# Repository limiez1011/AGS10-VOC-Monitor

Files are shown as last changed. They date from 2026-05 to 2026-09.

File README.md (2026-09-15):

[air quality monitor-bom.csv](https://github.com/user-attachments/files/27851702/air.quality.monitor-bom.csv)
# AGS10-VOC-Monitor
Battery-powered indoor air quality monitor that reads VOC every 60 seconds and displays it on an e-ink screen.

## Functionality
It uses an AGS10 TVOC sensor which samples the air every 60 seconds, when it's not sampling it goes into a sleep mode where the resistive heater turns off, the PCB includes an MCP73831 which charges LiPo batteries at 0.5A which is perfect for a 500mAh or 800mAh LiPo (1C/0.625C charge rate) The MCU is the seeed studios RP2040 which has a trace going from BATT+ to an ADC pin with a voltage divider so that we can know when to charge the batteries. The sample is then displayed on a 2.66in E-ink which is also updated every 60 seconds, It displays voltage and ppb.

## Bill of Materials
### (2 PCBS)
|Name |Purpose |Quantity|Total Cost (USD)|Link |Distributor|
|---|---|---|---|---|---|
|Passives |Caps,Resistors,Diodes|22 |1.00 | [link](https://jlcpcb.com/parts) |JLCPCB |
|MICROCHIP MCP73831T-2ATI/OT|lipo charger |2 |2.40 | [link](https://jlcpcb.com/partdetail/MicrochipTech-MCP73831T_2ATIOT/C14879) |JLCPCB |
|AGS10 |VOC sensor |2 |3.20 | [link](https://jlcpcb.com/partdetail/AGS10/C3012632) |JLCPCB |
|SEEED rp2040 |MCU |2 |11.30 | [link](https://www.tme.eu/ro/details/seeed-102010428/kituri-de-dezvoltare-altele/seeed-studio/xiao-rp2040/) |TME EU |
|PCB |PCBA |5 |17.00 | [link](https://jlcpcb.com/pcb-assembly) |JLCPCB |
|Waveshare 18321 |eink display |1 |14.28 | [link](https://www.tme.eu/ro/details/wsh-18321/hartie-electronica/waveshare/18321)|TME EU |

## Photos






## Build photos






## Build Instructions

- Create PCB jig
- Apply solder paste using stencil
- place components
- add to hotplate to melt solder
- solder mcu + eink
- flash firmware by pressing boot and adding the firmware file to the root directory
  and thats all.

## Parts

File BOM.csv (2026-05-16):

Name | Purpose | Quantity | Total Cost (USD) | Link | Distributor
Passives | Caps,Resistors,Diodes | 22 | 1.00 | https://jlcpcb.com/parts | JLCPCB
MICROCHIP MCP73831T-2ATI/OT | lipo charger | 2 | 2.40 | https://jlcpcb.com/partdetail/MicrochipTech-MCP73831T_2ATIOT/C14879 | JLCPCB
AGS10 | VOC sensor | 2 | 3.20 | https://jlcpcb.com/partdetail/AGS10/C3012632 | JLCPCB
SEEED rp2040 | MCU | 2 | 11.30 | https://www.tme.eu/ro/details/seeed-102010428/kituri-de-dezvoltare-altele/seeed-studio/xiao-rp2040/ | TME EU
PCB | PCBA | 5 | 17.00 | https://jlcpcb.com/pcb-assembly | JLCPCB
Waveshare 18321 | eink display | 1 | 14.28 | https://www.tme.eu/ro/details/wsh-18321/hartie-electronica/waveshare/18321/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 | TME EU

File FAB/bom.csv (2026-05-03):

Designator | Footprint | Quantity | Value | LCSC Part #
C1 | 402 | 1 | 100nF | C1525
C3, C4 | 603 | 2 | 4.7uF | C19666
D1 | 603 | 1 | LED_Small | C2286
D2 | SOD-123 | 1 | D_Schottky_Small | C8598
R1, R2 | 402 | 2 | 4.7K | C25900
R3 | 402 | 1 | 2K | C4109
R4 | 402 | 1 | 470 | C25117
R5, R6 | 402 | 2 | 100K | C25741
U1 | AGS10 | 1 | ~ | C3012632
U3 | SOT95P280X145-5N | 1 | MCP73831T-2ACI_OT | C14879

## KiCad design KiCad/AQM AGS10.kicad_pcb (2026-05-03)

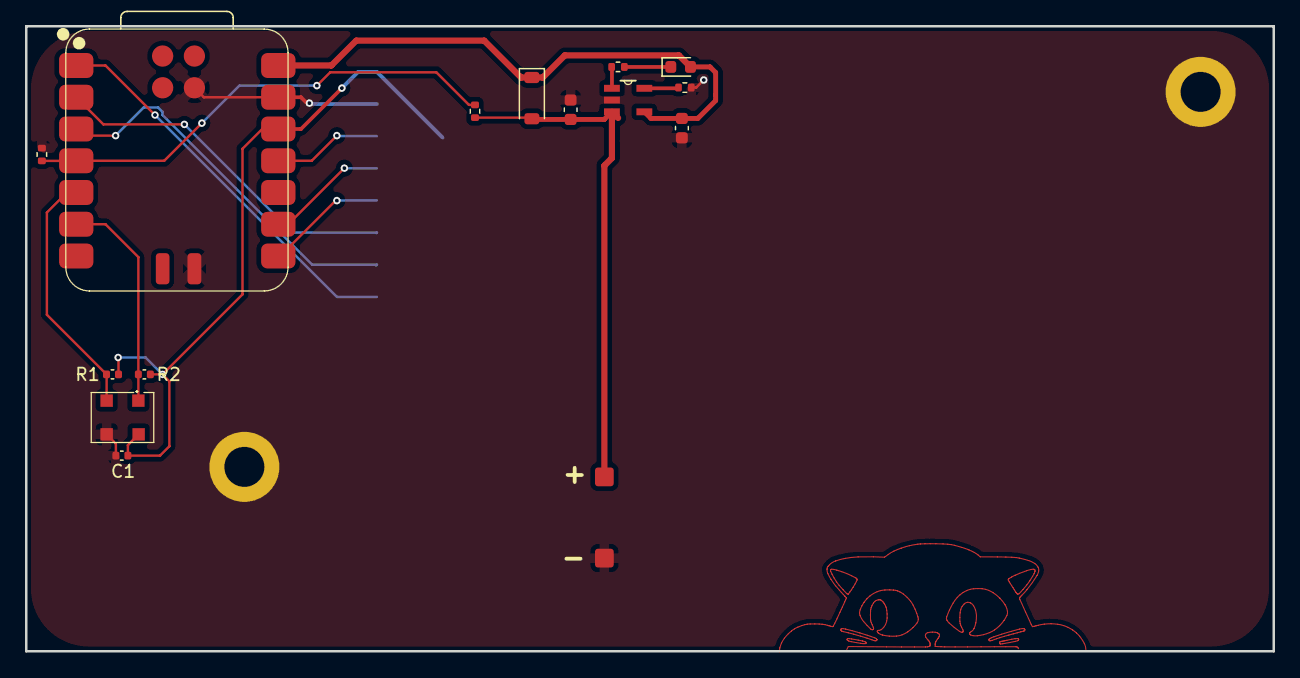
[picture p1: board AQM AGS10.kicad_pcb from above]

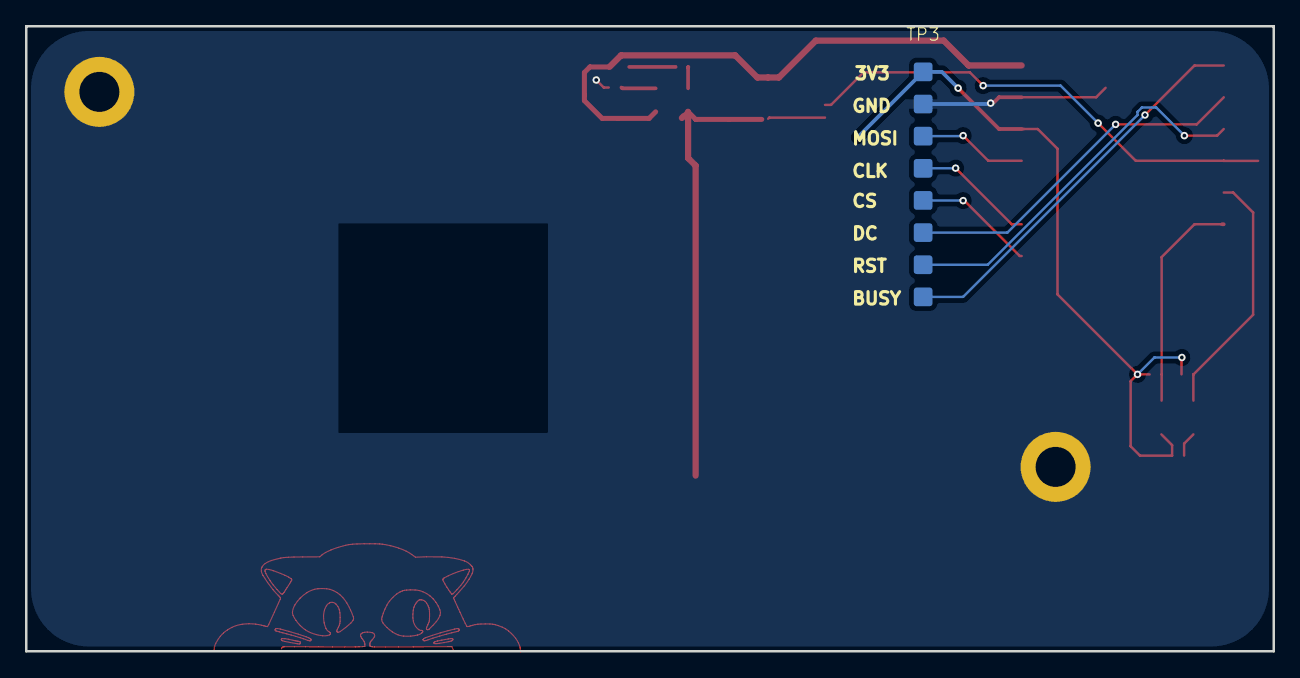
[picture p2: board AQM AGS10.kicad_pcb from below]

Board: 2 copper layers, 99.8 x 50.0 mm, 26 parts (8 on the bottom side), 16 nets.

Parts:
C1: 100nF; C_0402_1005Metric
C3, C4: 4.7uF; C_0603_1608Metric
D1: LED_Small; LED_0603_1608Metric
D2: D_Schottky_Small; D_SOD-123
H3, H4: MountingHole_Pad; MountingHole_3.2mm_M3_DIN965_Pad
R1, R2: 4.7K; C_0402_1005Metric
R3: 2K; R_0402_1005Metric
R4: 470; R_0402_1005Metric
R5, R6: 100K; R_0402_1005Metric
TP1: BATT-; padround
TP2, TP3, TP4, TP5, TP6, TP7, TP8, TP9, TP10: BATT+; padround
U1: AGS10
U2: XIAO-RP2040-SMD
U3: MCP73831T-2ACI_OT; SOT95P280X145-5N

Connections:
+3V3: C1.2, R1.1, R2.1, TP3.1 (1_1), U1.4, U2.12 (3V3)
+5V: C3.1, D1.2 (A), D2.1 (K), U2.14 (5V), U3.4 (VDD)
/BAT: C4.1, D2.2 (A), R5.1, TP2.1 (1_1), U3.3 (VBAT)
/BUSY: TP10.1 (1_1), U2.1 (GPIO26_A0_D0)
/CS: TP7.1 (1_1), U2.8 (GPIO1_D7_CSn_RX)
/DC: TP8.1 (1_1), U2.2 (GPIO27_A1_D1)
/MOSI: TP5.1 (1_1), U2.11 (GPIO3_D10_MOSI)
/RST: TP9.1 (1_1), U2.3 (GPIO28_A2_D2)
/SCL: R2.2, U1.1, U2.6 (GPIO7_D5_SCL)
/SCLK: TP6.1 (1_1), U2.9 (GPIO2_D8_SCK)
/SDA: R1.2, U1.2, U2.5 (GPIO6_D4_SDA)
/STAT: R4.2, U3.1 (STAT)
GND: C1.1, C3.2, C4.2, H3.1 (1_1), H4.1 (1_1), R3.2, R6.2, TP1.1 (1_1), TP4.1 (1_1), U1.3, U2.13 (GND), U2.16 (GND), U2.20 (GND), U3.2 (VSS)
unnamed: D1.1 (K), R4.1
unnamed: R5.2, R6.1, U2.4 (GPIO29_A3_D3)
unnamed: R3.1, U3.5 (PROG)

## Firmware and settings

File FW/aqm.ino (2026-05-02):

#include <Arduino.h>
#include <Wire.h>
#include <SPI.h>
#include <GxEPD2_BW.h>
#include <Fonts/FreeSans9pt7b.h>
#include <Fonts/FreeSansBold18pt7b.h>

#define EPD_CS    1
#define EPD_DC    27
#define EPD_RST   28
#define EPD_BUSY  26
#define AGS_SDA   6
#define AGS_SCL   7
#define BAT_PIN   29
#define LED_R     17
#define LED_G     16
#define LED_B     25

#define DISPLAY_INTERVAL_MS  60000UL
#define LOW_BAT_V            3.5f
#define LOW_BAT_FLASH_MS     100U
#define ADC_REF_V            3.3f
#define ADC_RES              4095.0f
#define BAT_DIVIDER          2.0f

#define AGS10_ADDR      0x1A
#define AGS10_REG_TVOC  0x00
#define AGS10_STATUS_OK 0x00
#define AGS10_WARMING   0x01

GxEPD2_BW<GxEPD2_266_GDEY0266T90, GxEPD2_266_GDEY0266T90::HEIGHT> display(
  GxEPD2_266_GDEY0266T90(EPD_CS, EPD_DC, EPD_RST, EPD_BUSY)
);

float         batV          = 0;
bool          lowBat        = false;
uint32_t      tvocPpb       = 0;
bool          warming        = true;
unsigned long lastDisplayMs = 0;

void ledOff() {
  digitalWrite(LED_R, HIGH);
  digitalWrite(LED_G, HIGH);
  digitalWrite(LED_B, HIGH);
}

void flashLed(bool r, bool g, bool b, uint16_t ms) {
  digitalWrite(LED_R, r ? LOW : HIGH);
  digitalWrite(LED_G, g ? LOW : HIGH);
  digitalWrite(LED_B, b ? LOW : HIGH);
  delay(ms);
  ledOff();
}

float readBatV() {
  uint32_t sum = 0;
  for (int i = 0; i < 8; i++) {
    sum += analogRead(BAT_PIN);
    delay(2);
  }
  return (sum / 8.0f / ADC_RES) * ADC_REF_V * BAT_DIVIDER;
}


uint8_t crc8(const uint8_t* data, uint8_t len) {
  uint8_t crc = 0xFF;
  for (uint8_t i = 0; i < len; i++) {
    crc ^= data[i];
    for (uint8_t b = 0; b < 8; b++) {
      crc = (crc & 0x80) ? (crc << 1) ^ 0x31 : (crc << 1);
    }
  }
  return crc;
}


bool readAgs10() {
  Wire.beginTransmission(AGS10_ADDR);
  Wire.write(AGS10_REG_TVOC);
  if (Wire.endTransmission(false) != 0) return false;

  if (Wire.requestFrom(AGS10_ADDR, (uint8_t)5) != 5) return false;

  uint8_t buf[5];
  for (int i = 0; i < 5; i++) buf[i] = Wire.read();

  if (crc8(buf, 4) != buf[4]) return false;

  warming  = (buf[0] == AGS10_WARMING);
  tvocPpb  = ((uint32_t)buf[1] << 16) | ((uint32_t)buf[2] << 8) | buf[3];

  return true;
}

const char* tvocLabel(uint32_t ppb) {
  if (ppb <= 220)  return "Excellent";
  if (ppb <= 660)  return "Good";
  if (ppb <= 1430) return "Moderate";
  if (ppb <= 2200) return "Poor";
  return "Very poor";
}

void updateDisplay() {
  display.setFullWindow();
  display.firstPage();
  do {
    display.fillScreen(GxEPD_WHITE);
    display.setTextColor(GxEPD_BLACK);
    display.setTextWrap(false);

    display.setFont(&FreeSans9pt7b);

  
    display.setCursor(4, 14);
    display.print(batV, 2);
    display.print("V");
    if (lowBat) {
      display.setCursor(50, 14);
      display.print(" LOW");
    }

 
    if (warming) {
      display.setCursor(display.width() - 76, 14);
      display.print("Warming up");
    }

    display.drawLine(0, 20, display.width(), 20, GxEPD_BLACK);

 
    display.setFont(&FreeSansBold18pt7b);
    char tvocStr[12];
    if (warming) {
      snprintf(tvocStr, sizeof(tvocStr), "---");
    } else {
      snprintf(tvocStr, sizeof(tvocStr), "%lu", tvocPpb);
    }
    int16_t x1, y1;
    uint16_t w, h;
    display.getTextBounds(tvocStr, 0, 0, &x1, &y1, &w, &h);
    display.setCursor((display.width() - w) / 2, 72);
    display.print(tvocStr);


    display.setFont(&FreeSans9pt7b);
    display.getTextBounds("ppb", 0, 0, &x1, &y1, &w, &h);
    display.setCursor((display.width() - w) / 2, 92);
    display.print("ppb");

    display.drawLine(0, 100, display.width(), 100, GxEPD_BLACK);


    const char* label = warming ? "Warming up..." : tvocLabel(tvocPpb);
    display.getTextBounds(label, 0, 0, &x1, &y1, &w, &h);
    display.setCursor((display.width() - w) / 2, 130);
    display.print(label);

  } while (display.nextPage());

  display.powerOff();
}

void setup() {
  pinMode(LED_R, OUTPUT);
  pinMode(LED_G, OUTPUT);
  pinMode(LED_B, OUTPUT);
  ledOff();
  analogReadResolution(12);

  Wire.setSDA(AGS_SDA);
  Wire.setSCL(AGS_SCL);
  Wire.begin();

  display.init(0);
  display.setRotation(1);


  Wire.beginTransmission(AGS10_ADDR);
  if (Wire.endTransmission() != 0) {
    while (true) { flashLed(true, false, false, 300); delay(300); }
  }

  flashLed(false, true, false, 200);
}

void loop() {
  unsigned long now = millis();

  if (now - lastDisplayMs >= DISPLAY_INTERVAL_MS) {
    if (!readAgs10()) {
      flashLed(true, false, false, 100);
    }

    batV   = readBatV();
    lowBat = batV < LOW_BAT_V;
    if (lowBat) flashLed(false, false, true, LOW_BAT_FLASH_MS);

    updateDisplay();
    lastDisplayMs = now;
  }
}

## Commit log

2026-05-03 Update README with Bill of Materials and photo
    Added detailed Bill of Materials and photo to README.
2026-05-14 Revise Bill of Materials in README
    Updated the Bill of Materials with new components and prices, including total costs and shipping estimates.
2026-05-16 Revise BOM and add external links in README
    Updated the Bill of Materials section and added links to external resources.
2026-05-16 Change PCB quantity in Bill of Materials
    Updated the Bill of Materials section to reflect the quantity of PCBs.
2026-05-16 Format Bill of Materials section in README.md
2026-05-16 Rename air quality monitor-bom (1).csv to BOM.csv
    [BOM.csv]
2026-09-15 Add build instructions to README
    Added build instructions section with steps for PCB assembly.
